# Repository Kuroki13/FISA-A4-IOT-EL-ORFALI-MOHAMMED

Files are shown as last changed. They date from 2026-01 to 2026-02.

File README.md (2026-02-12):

#  Projet IoT : "Un Campus Qui Vous Comprend"

 
 


> **Groupe 1 :** Développement et qualification d'un sous-système de contrôle environnemental (ECLSS) pour station spatiale.
>
> **Objectif :** Réalisation et validation d'un **Modèle d'Ingénierie (EM)** en environnement analogue (Salle de classe).

---

##  L'Équipe

| Membre | Rôle Technique | Responsabilités Mission |
| :--- | :--- | :--- |
| **Mohammed EL ORFALI** | Dev. Embarqué | Développement Firmware Capteur & Algorithmes de survie (Safety) |
| **Axel DELAR** | Ingénieur Radio | Protocoles de transmission & Validation Couverture Wi-Fi/4G |
| **Remy MOREEL** | Architecte Réseau | Architecture du (Gateway) & Gestion flux de données |
| **Léo SCHAEFFER** | Intégrateur Cloud | Développement du (Dashboard) & Stockage |

---

## Contexte & Problématique : "La Classe comme Station"

 



Dans une station spatiale (ISS), l'air est une ressource critique. Une augmentation du CO2 ou une baisse de pression n'est pas un simple inconfort, c'est une question de survie immédiate. Les délais de communication avec la Terre interdisent une gestion de crise 100% Cloud.

**Notre approche : Le "Module Pressurisé Autonome"**
Nous utilisons une salle de classe comme **environnement analogue** (volume clos, génération de CO2) pour qualifier un système capable de :

1.  **Survie (Edge Computing) :** Le module gère sa propre sécurité. Si le CO2 dépasse le seuil critique, l'alarme sonne **localement** et **instantanément**, sans attendre Internet.

---

## Architecture Technique (Modèle d'Ingénierie)

Le système suit une architecture IoT en couches stricte, adaptée aux contraintes spatiales simulées.



### 1. Zone de Perception
Le "Nez" du système. Il est autonome énergétiquement et décisionnellement.
* **Hardware :** Arduino (Avec ESP32) sur secteur & Powerbank (Simulation Batterie Secours).
* **Capteurs Critique :**
    * Qualité d'air : Grove Gas Sensor (MQ135 / Ref 101020078).
    * Environnement : Capteur Temp/Humidité (AM2302).
* **Sécurité :** Algorithme réflexe `IF CO2 > 1200ppm THEN Trigger_Alarm()`.
* **Protocole :** MQTT sur Wi-Fi local.

### 2. Zone Middleware
Le cerveau local du module.
* **Hardware :** PC Hôte.
* **Rôle Gateway :** Héberge le Broker MQTT (Mosquitto) et le moteur de flux (Node-RED).

### 3. Zone Application
La supervision distante pour les ingénieurs au sol.
* **Interface :** Dashboard Node-RED.
* **Données :** Télémétrie temps réel + Historique des incidents.

---

## Interface de Données

Le module transmet sa télémétrie toutes les 5 secondes sur le topic `eclss/télémetrie`.

**Format du Payload JSON :**
```json
{
        "id": "821ed53125562099",
        "type": "tab",
        "label": "GRAPHIQUES",
        "disabled": false,
        "info": "",
        "env": []
    },
    {
        "id": "c7015096d238237f",
        "type": "group",
        "z": "821ed53125562099",
        "name": "GRAPHIQUE SALLE 1",
        "style": {
            "stroke": "#000000",
            "fill": "#d1d1d1",
            "label": true,
            "color": "#000000"
        },
        "nodes": [
            "ec4d7a4e82cce2f2",
            "88a6b0668f27c40c",
            "658985ec2a1d724f",
            "656f1342826a0567",
            "46b9011460992d86",
            "f8d7d4595bd604d4",
            "945a7696eff37191"
        ],
        "x": 284,
        "y": 119,
        "w": 362,
        "h": 242
    }
}

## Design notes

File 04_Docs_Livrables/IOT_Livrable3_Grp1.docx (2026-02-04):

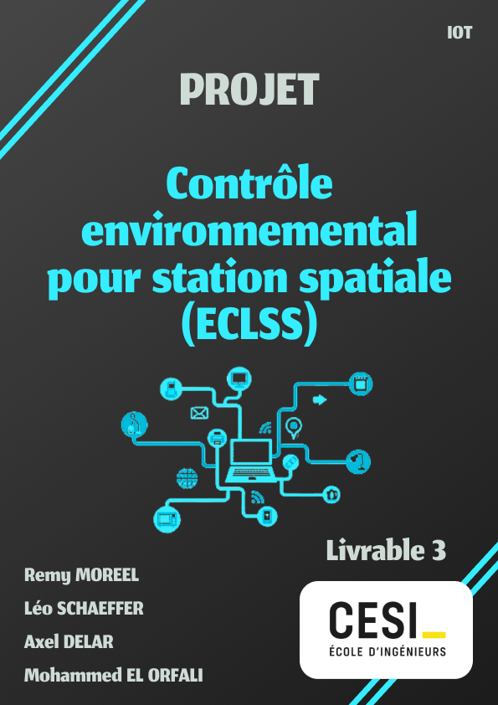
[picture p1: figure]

# Table des matières

# 1. Introduction

Après trois semaines d’analyse et de conception, ce livrable marque le passage de la théorie à la pratique. L’objectif n’est plus seulement de proposer une architecture cohérente, mais de démontrer la viabilité technique du système à travers un prototype fonctionnel.

Dans ce cadre, nous avons réalisé un Proof of Concept (POC) opérationnel mettant en œuvre une chaîne complète de communication entre capteurs, une passerelle Edge et notre consommateur, en nous appuyant sur un protocole applicatif adapté aux objets contraints. Le choix s’est porté sur MQTT, en raison de sa légèreté, de son modèle de communication publication/souscription.

Ce livrable 3 présente :

- Une démonstration fonctionnelle du flux de données (capteurs – Broker MQTT – consommateur)
- Un schéma d’architecture de communication
- Une note protocolaire justifiant les choix techniques réalisés

Enfin, il y aura également une partie sur la sécurité du prototype. Des mesures de base, inspirées des recommandations de la norme ETSI EN 303 645, ont été intégrées afin de garantir un minimum de protection pour notre dispositif.

# 2. Présentation de l’équipe

Voici notre équipe pour la réalisation de ce projet :

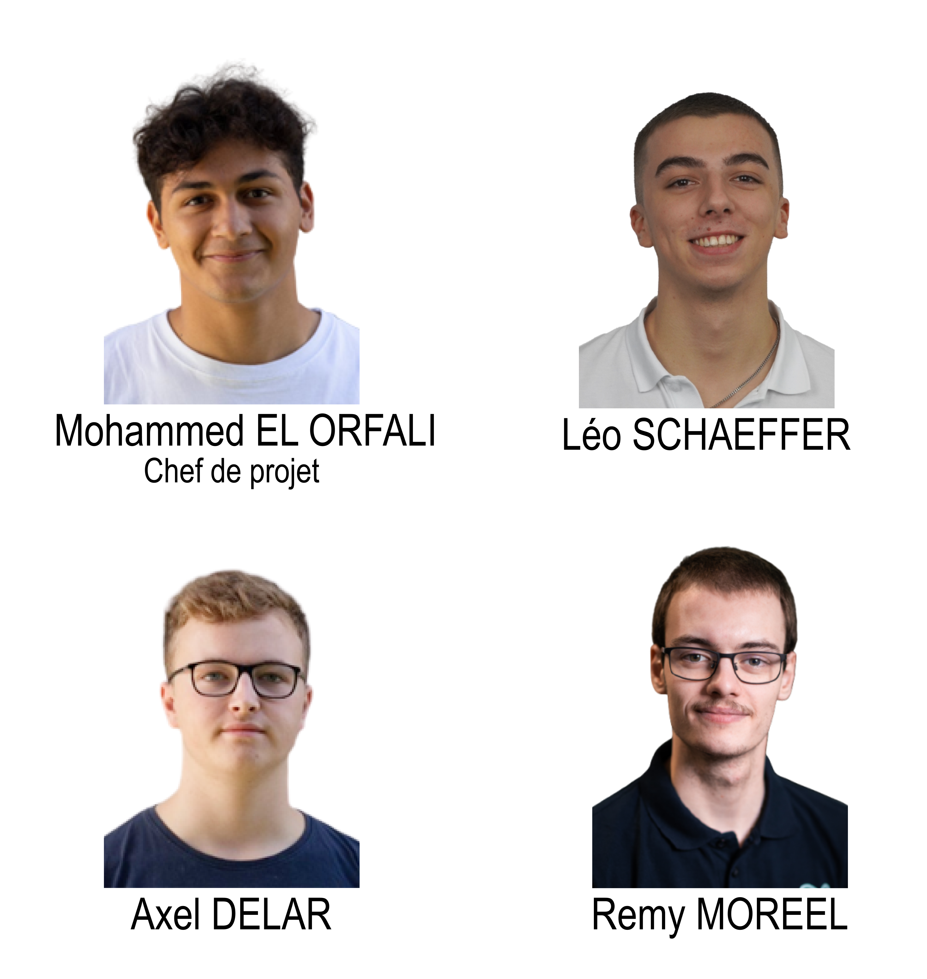
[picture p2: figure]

# 3. Schéma d’architecture de communication

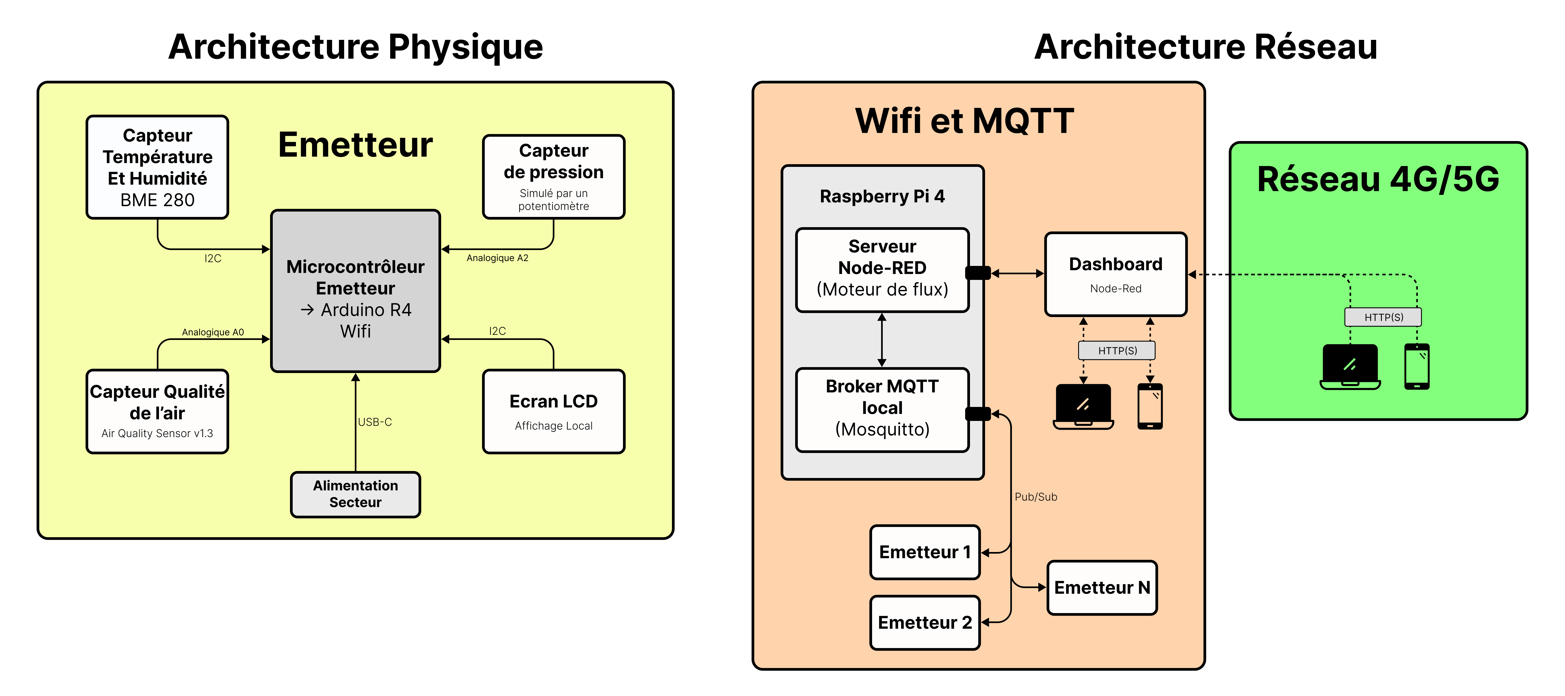
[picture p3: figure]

Ce schéma montre l’architecture globale de votre prototype, en séparant la partie physique (les objets contraints) et la partie réseau autour de MQTT.

Dans le bloc « Architecture Physique », on voit les cartes Arduino émettrices avec leurs capteurs (température/humidité BME280, qualité de l’air, pression) et l’écran LCD, tous reliés au microcontrôleur Arduino R4 WiFi qui mesure les grandeurs et publie les données.

Dans le bloc « Wifi et MQTT », la Raspberry Pi 4 joue le rôle de passerelle Edge : elle héberge le broker Mosquitto et le serveur Node‑RED qui reçoit les messages, les traite et alimente le dashboard.

Enfin, le bloc « Réseau 4G/5G » illustre l’accès distant : le dashboard Node‑RED peut être consulté depuis un smartphone ou un autre PC via HTTPS, pour visualiser en temps réel les mesures issues des Arduino publiées en MQTT.

Le déroulé complet de ce flux, depuis la mesure sur les capteurs jusqu’à l’affichage sur le dashboard, sera détaillé dans la suite du rapport.

# 4. Note protocolaire

### I) Choix protocole MQTT

Dans le cadre de ce projet, le protocole MQTT (Message Queuing Telemetry Transport) a été retenu pour assurer la communication entre les capteurs, la passerelle Edge et les consommateurs de données. MQTT est particulièrement adapté aux objets contraints, grâce à sa légèreté, à sa faible consommation de bande passante et à sa simplicité de mise en œuvre.

Le protocole repose sur un modèle publication / souscription, qui permet de découpler les producteurs de données (capteurs) des consommateurs (applications, dashboards). Ce découplage facilite l’évolutivité du système et limite les dépendances entre les composants, ce qui est particulièrement pertinent dans un contexte IoT.

Dans notre architecture, le broker MQTT Mosquitto est déployé localement sur une Raspberry Pi, qui joue le rôle de passerelle Edge. Cette passerelle centralise les échanges, assure la réception des données issues des capteurs et leur redistribution vers les consommateurs.

### II) Modèle de communication : publication/souscription

Les cartes Arduino, représentant les objets contraints du système, publient périodiquement les mesures issues des capteurs (température, pression, humidité, qualité de l’air). Ces données sont envoyées vers le broker MQTT sans connaissance directe des consommateurs.

Le dashboard Node-RED s’abonne aux topics correspondants afin de recevoir les données en temps réel. Ce modèle permet :

- D’ajouter ou de retirer des consommateurs sans modifier les capteurs,
- De centraliser le traitement au niveau de la passerelle Edge,
- De limiter les échanges inutiles sur le réseau.

Pour le moment, la communication est principalement unidirectionnelle (capteurs → consommateurs). Toutefois, l’architecture prévoit également une communication descendante (passerelle → capteurs), notamment pour le pilotage à distance d’actionneurs tels qu’un buzzer.

### III) Organisation des topics MQTT

Les topics ont été organisés selon une logique par type de donnée, avec un préfixe commun permettant d’identifier le projet :

- eclss/temperature
- eclss/pression
- eclss/humidite
- eclss/airquality
- eclss/buzzer/salle1
- eclss/buzzer/salle2

Les mesures provenant de plusieurs salles sont publiées sur un même topic, accompagnées d’un identifiant de l’Arduino émetteur dans la charge utile du message. Le tri et la séparation des données sont ensuite réalisés au niveau de Node-RED, qui filtre les messages en fonction de cet identifiant.

Ce choix nous permet :

- De limiter le nombre de topics à gérer,
- De simplifier la configuration côté capteurs,
- De centraliser la logique de traitement et de routage sur la passerelle Edge.

Les topics eclss/buzzer/salleX sont réservés à une évolution future du système, permettant l’envoi de commandes depuis le dashboard vers les capteurs afin d’activer des actionneurs à distance.

### IV) Qualité de service (QoS)

Les messages MQTT sont publiés avec un niveau de qualité de service QoS 1. Ce niveau garantit que chaque message est reçu au moins une fois par le broker et les abonnés, grâce à un mécanisme d’accusé de réception. En contrepartie, ce mode peut entraîner une duplication ponctuelle des messages, qui est gérée au niveau applicatif.

Ce choix constitue un compromis entre fiabilité et légèreté. Les données issues des capteurs sont envoyées à une fréquence d’une seconde et ne sont pas critiques au sens strict, mais une perte répétée de messages pourrait dégrader la lisibilité des mesures sur le dashboard. Le QoS 1 permet ainsi d’améliorer la fiabilité des échanges tout en conservant une charge réseau et une complexité limitée, compatibles avec un prototype IoT.

Ce niveau de QoS est également cohérent avec une architecture Edge locale, où la latence reste faible et où le surcoût induit par les accusés de réception demeure acceptable.

### V) Gestion des sessions et des messages retain

Les messages MQTT sont publiés sans option retain. Ainsi, seuls les nouveaux messages sont transmis aux abonnés, et aucune valeur précédente n’est automatiquement envoyée lors de la connexion d’un nouveau client. Ce comportement est adapté à un système où les données sont mises à jour très fréquemment et où les valeurs passées présentent peu d’intérêt.

Les clients MQTT utilisent une clean session activée. Les capteurs étant en fonctionnement continu, hormis lors de redémarrages ponctuels, il n’est pas nécessaire de conserver des sessions persistantes ou des messages en attente. Ce choix simplifie la gestion des connexions et reste cohérent avec le caractère non critique des données.

# 5. Sécurité “baseline”

D’un point de vue sécurité et cybersécurité de notre dispositif, on se base sur la norme ETSI EN 303 645. Celle-ci définit un socle dit « baseline » d’exigences en termes de cybersécurité et de protection des données, pour les objets connectées (soit, l’IoT).

La norme met à disposition 13 mesures :

- Pas de mots de passe universels par défaut : Il est évident que nous n’utilisons aucun mot de passe par défaut (123456, P@ssw0rd, admin, etc.). Chaque mot de passe utilisé dans le projet est généré aléatoirement et stocker en local dans un fichier secrets.h (non disponible sur le repository GitHub).
- Gérer les signalements de vulnérabilités : En d’autres termes, si un incident est repéré par un client ou autres, sur un objet connecté que nous avons conçu, nous avons le devoir d’y remédier.
- Maintenir le logiciel à jour : Si des mises à jour de composants, ou des failles critiques dans le logiciel sont détectées, nous avons le devoir d’en faire une mise à jour de sécurité.
- Stocker de façon sûre les paramètres sensibles : Cela se rapporte à ce qui à été mentionné dans le point 1. Toutes nos données confidentiels et paramètres (Pin des capteurs, mots de passe Wi-Fi, port MQTT, Topics de communication) sont stockées dans un fichier secrets.h local.
- Communiquer de façon sûre : Toutes nos communications sont protégées par le protocole TLS au niveau du transport, ainsi que par un chiffrement HMAC au niveau applicatif. En faisant cela, les envois/réceptions de messages sont sécurisées.
- Minimiser la surface d’attaque exposée : En d’autres termes, limité le nombre de connexions et les données envoyées. Dans notre cas, nous faisons une sélection des données avant l’envoie via MQTT dans un souci de sécurité et d’optimisation.
- Assurer l’intégrité logicielle : Pour ce cas, nous sommes entrain de mettre en place une blockchain, qui permettra la vérification de l’intégrité.
- Sécuriser les données personnelles : Dans notre cas, nous ne stockons pas de données personnelles.
- Résilience aux pannes : Nous avons choisi pour ce point d’avoir nos émetteurs sur secteur, avec une batterie de secours en cas de coupure, de même que pour le routeur que l’on utilise pour les communications en local. Ainsi, s’il y a un problème nous stockons les données en local, afin de les renvoyées lors du rétablissement.
- Exploiter la télémétrie (logs) de manière utile : Pour ce point, nous avons pour projet d’instaurer une analyse prédictive sur notre serveur Node-Red, afin de pourvoir anticiper des pannes, de mauvaises données, etc.
- Faciliter la suppression des données utilisateur : Non concernées car nous ne stockons pas de données utilisateurs.
- Rendre l’installation et la maintenance simples : Pour cela, nous avons conçu un boitier permettant l’accès facile à tous les composants. De même, ces composants sont facilement trouvables et remplaçable.
- Valider les entrées : Par exemple, prévoir les injections SQL. Nous ne sommes pas concernées par ce point car nous n’attendons aucune entrée utilisateur.

Par ces différents points, nous garantissons la sécurité aux utilisateurs de notre prototype.

# 6. PoC

Pour ce livrable, il nous était demandé de fournir une vidéo de démonstration, un Proof of Concept du projet. Pour cela, nous avons tourné une vidéo contenant une démo de flux de données, d’un Arduino émetteur vers le serveur sur Raspberry Pi, utilisant le protocole MQTT.

Cette vidéo est disponible dans le dossier Moodle de ce livrable et contient les différents détails de notre configuration MQTT (topics, QoS, journal du Broker).

Dans un premier temps, la vidéo présente les deux cartes Arduino sur lesquelles sont connectés les différents capteurs. Ces cartes représentent les objets contraints du système et sont chargées de mesurer les données physiques.

Ensuite, nous affichons sur le PC le moniteur série d’une des cartes Arduino. Cela permet de visualiser en temps réel les valeurs mesurées par les capteurs ainsi que les données qui sont envoyées vers le réseau, afin de vérifier le bon fonctionnement de la collecte et de l’émission des messages.

La vidéo se concentre ensuite sur la Raspberry Pi 4, qui joue le rôle de passerelle Edge. Celle-ci héberge le broker MQTT. Nous affichons le journal du broker en temps réel, ce qui permet d’observer directement les messages échangés, les connexions des clients et les publications sur les différents topics. À ce stade, l’ensemble des topics est affiché afin d’avoir une vision globale des échanges, même s’il serait possible de se limiter à un topic spécifique selon les besoins.

Nous présentons ensuite le point d’accès Wi-Fi, qui permet d’interconnecter l’ensemble des équipements du prototype : les cartes Arduino, la passerelle Edge et les dispositifs consommateurs. Ce réseau local constitue le support de communication du système.

Enfin, la vidéo montre l’ordinateur client sur lequel est affiché le dashboard Node-RED. Pour des raisons de simplicité de configuration, le dashboard est temporairement hébergé sur cet ordinateur, mais il sera intégré directement à la Raspberry Pi dans la version finale. On peut alors observer que les jauges du dashboard se mettent à jour en temps réel à chaque nouvelle donnée reçue via MQTT, ce qui valide le bon fonctionnement de la chaîne complète.

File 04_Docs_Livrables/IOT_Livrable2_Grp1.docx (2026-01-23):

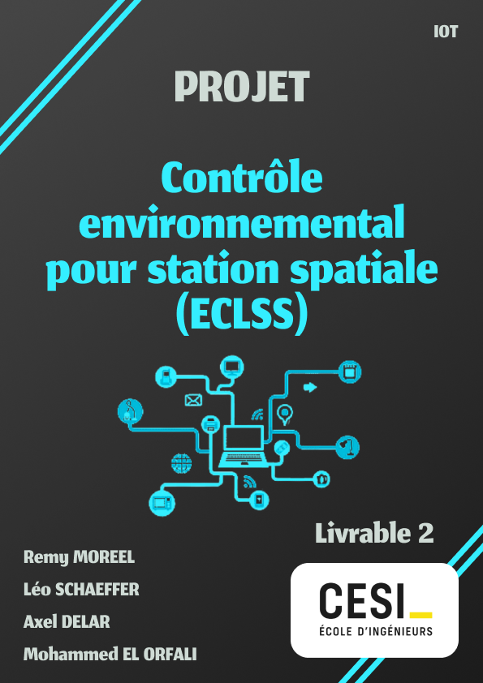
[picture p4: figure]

Livrables attendus (https://scenari.cesi.fr/scenari/cas/FISA_INFO_A4_IoT_Systemes_communicants_ERP/FISA_INFO_A4_IoT_Systemes_communicants_2526_1.html)

1. Matrice multicritère (2–3 pages) : comparaison BLE / ZigBee / Wi-Fi / LoRaWAN / NB-IoT / (Sigfox) sur : portée, débit, conso, coût, densité, dépendance opérateur, interopérabilité ; classement + justification.
2. Schéma d’architecture de communication (1 page) : couches capteur→passerelle→(Edge)→Cloud, flux montants/descendants, points de décision (temps réel vs différé).
3. Note “opérateur vs privé” (½ page) : analyse propriétaire (Sigfox/NB-IoT) vs déploiement privé (LoRaWAN) selon vos contraintes campus.
4. Trace sécurité minimale (¼ page) : “comment le choix techno respecte ETSI EN 303 645 (baseline)”.

# Table des matières

# 1. Introduction

Dans un contexte où la fiabilité, la réactivité et la continuité de service sont des exigences critiques, ce rapport présente la conception et le prototypage d’un système de surveillance IoT appliqué à un module de contrôle environnemental et de support-vie (Environmental Control and Life Support System – ECLSS).

L’objectif principal est d’assurer le monitoring en temps réel de paramètres vitaux tels que la pression, la qualité de l’air et la température, tout en garantissant une résilience élevée face aux défaillances d’infrastructure réseau ou matérielle.

Dans un premier temps, ce document expose une analyse multicritère des protocoles de communication IoT (LoRaWAN, Sigfox, Wi-Fi, LTE-M, etc.), ayant conduit au choix d’une architecture hybride Wi-Fi / LTE-M, adaptée aux contraintes de débit, de latence et de disponibilité du système.

Nous détaillerons ensuite l’architecture technique retenue, fondée sur une approche Edge-First, s’appuyant sur des composants tels que l’Arduino R4, le Raspberry Pi et la plateforme Node-RED, afin de sécuriser les flux de données et de rapprocher les décisions critiques du terrain.

Enfin, nous analyserons la conformité du système aux exigences de cybersécurité définies par la norme ETSI EN 303 645, garantissant un niveau de sécurité adapté aux environnements IoT critiques.

Présentation de l’équipe

Voici notre équipe pour la réalisation de ce projet :


# 2. Analyse Comparative et Sélection Technologique

## I. Objectif de l’analyse

Afin d’identifier la technologie la plus adaptée à notre cas d’usage, nous avons confronté les principaux protocoles du marché. Nous avons mené une analyse comparative des principaux protocoles IoT disponibles sur le marché.

Cette étude s’appuie sur les critères critiques du projet, à savoir :

- La portée de communication,
- La consommation énergétique,
- Le débit de données,
- La capacité à gérer la mobilité,
- La topologie réseau.

## II. Comparaison des protocoles IOT

Le tableau ci-dessous synthétise les caractéristiques techniques des technologies étudiées et met en évidence leurs domaines d’application.

Protocole | Catégorie | Portée | Débit | Consommation | MOBILITE | Type de réseau
Zigbee | WPAN / LAN | Courte (10-100m) | Moyen (250 kbps) | Très Faible | Non (Local) | Maillé (Mesh)
BLE | WPAN | Très courte (<50m) | Moyen (1-2 Mbps) | Très Faible | Oui (Portable) | Point-à-point / Étoile
LoRaWAN | LPWAN | Très Longue (Km) | Très Faible | Très Faible | Moyenne (Sans handover) | Étoile
Sigfox | LPWAN | Très Longue (Km) | Ultra Faible | Très Faible | Moyenne (Sans handover) | Étoile
Wi-Fi | WLAN | Moyenne (100m) | Très Élevé | Élevée | Faible (Local) | Étoile
LTE-M | LPWAN (Cellulaire) | Longue (Nationale) | Moyen (1 Mbps) | Moyenne/Faible | Excellente | Étoile (Cellulaire)
NB-IoT | LPWAN (Cellulaire) | Longue (Nationale) | Faible (250 kbps) | Faible | Mauvaise Handover | Étoile (Cellulaire)

Tableau 1 : Matrice comparative des protocoles de communication IoT

## III. Architecture réseau retenue

Au regard des contraintes de notre environnement critique (temps réel, fiabilité, évolutivité), nous avons retenu une architecture de communication hiérarchisée à deux niveaux.

Niveau local (LAN)

La couche perception communique localement via le protocole Wi-Fi.

Ce choix est motivé par :

- Une bande passante élevée,
- Une latence très faible,
- La compatibilité native IP, permettant le traitement et l’agrégation des données en temps réel sur site.

Les données sont centralisées par une passerelle IoT, basée sur un Raspberry Pi, jouant le rôle de nœud de bordure (Edge Node).

Niveau étendu (Backhaul cellulaire – optionnel)

En option, et sous réserve de disponibilité en fin de projet, une seconde liaison de communication sera mise en place afin :

- D’exfiltrer les données vers le Cloud,
- De permettre l’accès au tableau de bord à l’échelle internationale.

Dans ce scénario, la passerelle s’appuie sur une liaison LTE/4G. Ce choix de backhaul cellulaire garantit une connectivité indépendante de l’infrastructure filaire locale, assurant ainsi la continuité de service, y compris dans des environnements contraints ou isolés.

# 3. Technologies retenues

## IV. Protocole Wi-Fi

Protocole: Wi-Fi (IEEE 802.11 b/g/n/ax)

Présentation : Le standard mondial pour les réseaux locaux sans fil à haut débit. En IoT, il est utilisé pour les objets connectés au secteur nécessitant le transfert de gros volumes de données ou une interaction temps réel.

Caractéristiques techniques

Critère | Valeur
Débit | Très Élevé (11 à +1000 Mbit/s)
Portée | Moyenne (50 à 100 m)
Fréquence | 2.4 GHz / 5 GHz
Topologie | Étoile
Latence | Très Faible (ms)
Consommation | Élevée (Très élevée par rapport aux autres)
Sécurité | WPA2 / WPA3
Standard/Proprio | Standard (IEEE / Wi-Fi Alliance)

Avantages / Inconvénients

Avantages | Inconvénients
Débit énorme (vidéo possible). | Consommation d'énergie prohibitive pour les piles.
Infrastructure déjà présente partout. | Portée limitée par les murs.
Coût matériel faible et IP native. | Procédure d'appairage (SSID/Mot de passe) parfois pénible.

Cas d’usage : Caméras de surveillance, enceintes connectées, électroménager, écrans publicitaires et notre projet ECLSS

## V. Protocol LTE-M

Protocole: LTE-M (Long Term Evolution for Machines)

Présentation : Technologie cellulaire (4G) optimisée pour l'IoT. Elle utilise les antennes relais des opérateurs téléphoniques. Elle offre un compromis entre débit (suffisant pour la voix) et économie d'énergie, avec une excellente gestion de la mobilité.

Caractéristiques techniques

Critère | Valeur
Débit | Moyen-Bas (~375 kbit/s à 1 Mbit/s)
Portée | Longue (Couverture nationale 4G)
Fréquence | Bandes Licenciées (4G)
Topologie | Étoile (Cellulaire)
Latence | Faible à Moyenne (ms à s)
Consommation | Moyenne (Plus que LoRa, moins que 4G standard)
Sécurité | Carte SIM + Chiffrement Opérateur (Très haute)
Standard/Proprio | Standard (3GPP / Opérateurs)

Avantages / Inconvénients

Avantages | Inconvénients
Gère parfaitement la mobilité (Handover sans coupure). | Abonnement carte SIM payant obligatoire.
Débit suffisant pour la voix (VoLTE) et les mises à jour. | Consomme plus que Sigfox/LoRaWAN.
Qualité de service garantie (Bande licenciée). | Couverture dépendante de l'opérateur.

Cas d’usage : Traceurs de flotte de véhicules, bracelets de santé pour seniors (avec voix), terminaux de paiement mobiles et notre projet ECLSS

# 4. Stratégie de Déploiement : Réseau Opéré vs Réseau Privé

Sigfox et NB-IoT représentent des solutions propriétaires gérées par des opérateurs, tandis que LoRaWAN permet un déploiement privé autonome. Nous allons analyser les contraintes typiques d'un campus (superficie limitée ~1-5 km², bâtiments denses, besoins en fiabilité pour capteurs IoT comme tracking d'actifs ou monitoring énergétique, budget modéré). Pour un campus, le privé offre contrôle mais demande investissement initial, contre la simplicité des opérateurs au prix de dépendance. Pour notre projet nous n’utiliserons pas ces technologies et nous n’avons pas exactement le même contexte que le campus.

## I. Opérateur Propriétaire : Sigfox

Sigfox utilise un réseau mondial propriétaire ultra-basse consommation pour messages courts (12 octets). Déploiement pas optimisé côté campus, car opérateur gère l'infrastructure via abonnements (~1-2€/an/capteur).

## VI. Opérateur Propriétaire : NB-IoT

NB-IoT est une technologie cellulaire 4G/5G LPWAN des opérateurs comme Orange ou SFR, avec bonne pénétration en intérieur. Pas de déploiement local requis, facturation par data (~0.5-5€/an/capteur selon volume). Convient aux campus urbains couverts, avec QoS garantie mais coûts récurrents élevés pour gros volumes.

## VII. Déploiement Privé : LoRaWAN

LoRaWAN est open-source, déployé en privé via 1-3 passerelles (~500-5000€ chacune) couvrant un campus entier. Contrôle total (sécurité, QoS), bidirectionnel, scalable jusqu'à 1000s capteurs sans abonnement externe. Rentable dès 300 appareils, parfait pour contraintes campus (couverture indoor/outdoor personnalisée).

## VIII. Tableau Comparatif

Critère | Sigfox (Propriétaire) | NB-IoT (Propriétaire) | LoRaWAN (Privé)
Déploiement Campus | Aucun (réseau opérateur) | Aucun (réseau cellulaire) | 1-3 passerelles (1-2 mois setup)
Coût Initial (100 capteurs) | 500-1500€ modules + abos | 1000-3000€ modules + abos | 2500-17000€ (CAPEX only)
Coût Récurrent | 3000-6000€/5ans | Moyen-élevé par data | Zéro (propriétaire)
Couverture Campus | Bonne si zone opérateur | Excellente indoor (pénétration) | Optimale (ajustable)
Débit/Bidirectionnel | Faible uplink only ~100msg/j | Moyen, bidir. fiable | Élevé, bidir. configurable
Contraintes Campus | Dépendance opérateur, faillites passées | Couverture variable rurale | maintenance IT

En conclusion, aucune de ces solutions (Sigfox, NB-IoT propriétaires ou LoRaWAN privé) ne s'avère pas adaptée aux contraintes spécifiques d'un campus ou d'un espace clos. Elles ont toutes des limites en termes de coût récurrent ou de dépendance externe. Des alternatives comme Wi-Fi ou réseaux mesh zigbee conviendraient mieux pour une maîtrise optimale dans cet environnement.

# 5. Architecture de Communication et Flux de Données

Cette section détaille l'architecture technique mise en place pour le système ECLSS. Elle repose sur une architecture IoT modulaire divisée en 4 zones fonctionnelles, allant de la perception physique jusqu'à la visualisation distante via réseau cellulaire.

## I. Schéma d’architecture global

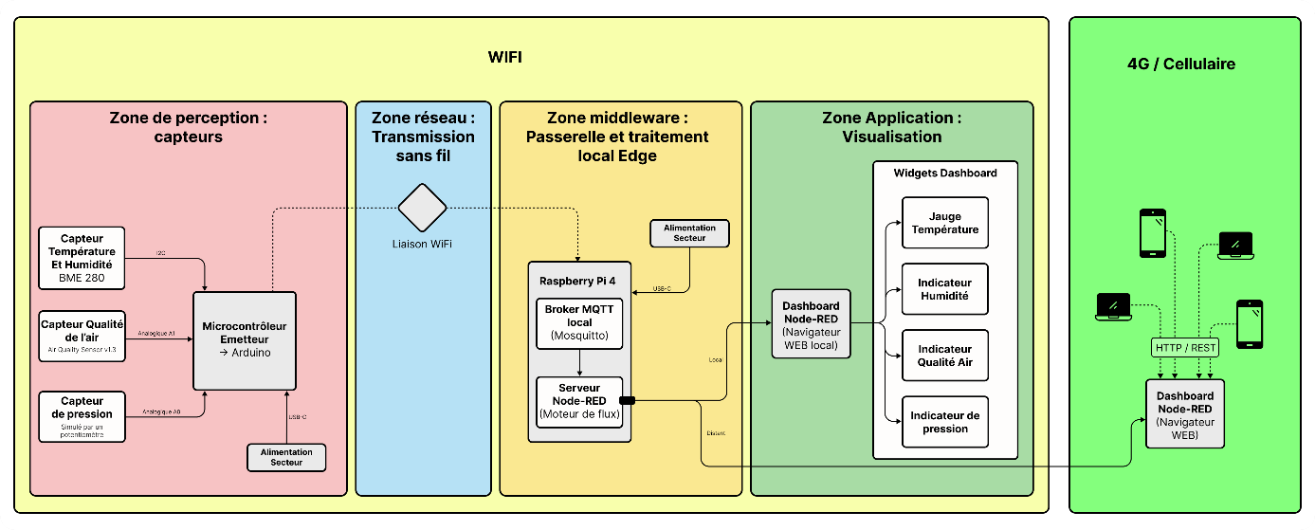
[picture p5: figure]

Figure 1 : Architecture global

## IX. Description des Zones

1. Zone de Perception (Capteurs)

- Matériel : Microcontrôleur Arduino (Emetteur).
- Instrumentation :
  - BME 280 : Mesure de la température et de l'humidité (Liaison I2C).
  - Air Quality Sensor v1.3 : Mesure de la qualité de l'air (Liaison Analogique A1).
  - Capteur de Pression (Simulé) : Surveillance de la pressurisation cabine (Liaison Analogique A0).
- Rôle : Acquisition des données brutes, conversion numérique et transmission vers la passerelle.

2. Zone Réseau (Transmission)

- Protocole : Wi-Fi (IEEE 802.11).
- Fonction : Assure le transport sans fil des messages MQTT entre le microcontrôleur et la passerelle. Cette zone crée un réseau local (LAN) dédié à la station.

3. Zone Middleware (Edge Computing)

- Support : Raspberry Pi 4 (Alimenté sur secteur).
- Composants Logiciels :
  - Broker MQTT (Mosquitto) : Agit comme le chef d'orchestre des données. Il reçoit les publications de l'Arduino et les distribue.
  - Serveur Node-RED : Moteur de flux qui traite les données, applique la logique métier (seuils d'alerte) et héberge l'interface graphique.
- Rôle : Cette couche "Edge" permet un traitement local des données critiques, garantissant une autonomie du système même sans connexion internet.

4. Zone Application & Connectivité 4G

- Visualisation : Dashboard Node-RED accessible via navigateur Web. Il affiche les jauges (Température, Humidité, Qualité Air, Pression) en temps réel.
- Accès Distant (4G/Cellulaire) : L'interface est rendue accessible à l'extérieur (Smartphones, PC portables) via une liaison HTTP/REST sur le réseau cellulaire. Cela permet la supervision de la station depuis n'importe quel point du globe (Terre).

## X. Flux de Données et Points de Décision

L’architecture repose sur une stratégie de défense en profondeur, dans laquelle les décisions critiques sont prises au plus près du matériel, tandis que les fonctions d’analyse, de supervision et de contrôle à distance sont déportées vers la passerelle Edge et, le cas échéant, vers le Cloud.

### Nœud capteur – Zone de perception (Arduino R4)

Le nœud capteur constitue le premier niveau de traitement (Edge Computing – Niveau 0). Il est responsable des réactions immédiates et de l’acquisition des données brutes.

Action A – Sécurité réflexe (Hard Real-Time)

Cycle de traitement : Lecture analogique (A0 – pression) → comparaison avec le seuil critique → si pression < 980 hPa → activation immédiate des actionneurs locaux (LED rouge, buzzer).

Justification : Cette boucle de sécurité s’exécute en moins de 1 ms et fonctionne de manière totalement autonome. Elle garantit une alerte immédiate de l’équipage, même en cas de :

- Coupure du réseau Wi-Fi,
- Défaillance de la passerelle Raspberry Pi.

Ce mécanisme assure ainsi une résilience maximale du système.

Action B – Télémétrie

Cycle de traitement : Lecture des capteurs (I2C / analogique) → sérialisation des données au format JSON (ex. {"ID_MAC": 3D-0F-FJ-EK-FJ, "val" : "980"}) → publication MQTT sur le topic eclss/pressure.

Fréquence :

- Envoi périodique toutes les 2 secondes afin de limiter la charge réseau.
- Envoi immédiat en cas de déclenchement d’alarme.

### Réseau local – Zone de transmission (Wi-Fi)

Rôle : Assurer le transport des messages JSON entre le nœud capteur et la passerelle Edge.

Caractéristiques : Contrairement aux protocoles LPWAN (LoRa, Sigfox), le Wi-Fi est maintenu en mode actif (Keep-Alive).

Avantages :

- Latence de transmission très faible (< 10 ms),
- Capacité à transporter des charges utiles importantes (trames JSON complètes),
- Absence de fragmentation ou de compression complexe.

### Passerelle / Middleware – Zone Edge (Raspberry Pi 4)

Le Raspberry Pi agit comme le centre de coordination du système et le point de transition vers l’extérieur.

Rôle 1 – Broker et distribution (Mosquitto)

- Réception des messages MQTT en provenance de l’Arduino.
- Distribution des messages aux abonnés locaux :
  - Node-RED

Rôle 2 – Visualisation et logique métier (Node-RED)

- Décodage des messages JSON.
- Mise à jour en temps réel des jauges du Dashboard local.

Rôle 3 – Passerelle WAN

- Exposition sécurisée de l’interface Web du Dashboard.
- Accès distant possible via la liaison cellulaire 4G/LTE-M.

### Réseau étendu – Zone WAN (4G / LTE-M)

Technologie :

- Partage de connexion via USB (tethering),
- Ou modem LTE-M sous forme de HAT.

Rôle : Fournir un backhaul Internet indépendant de l’infrastructure filaire locale.

Fonctionnalités :

- Accès au Dashboard Node-RED depuis un terminal distant (smartphone, PC),
- Utilisation d’une adresse IP publique ou d’un tunnel VPN/Cloud sécurisé.

### Flux descendant – Télécommande (Utilisateur → Capteur)

Ce flux permet l’interaction humaine à distance et le contrôle du système.

Interface utilisateur : Depuis un smartphone connecté en 4G, l’opérateur sélectionne l’action « Acquitter l’alarme » sur le Dashboard Web.

Traitement côté passerelle :

- Node-RED reçoit la requête HTTP,
- Génération d’un message MQTT de commande (ex. {"cmd": "RESET"}),
- Publication sur le topic eclss/control.

Exécution côté capteur :

- L’Arduino, abonné au topic, reçoit la commande via sa fonction callback (),
- Désactivation immédiate du buzzer et retour à l’état nominal.

# 6. Conformité et Sécurité (ETSI EN 303 645)

Le choix technologique du projet a été guidé par les exigences de sécurité de base définies par la norme ETSI EN 303 645, qui vise à renforcer la cybersécurité des objets connectés.

Tout d’abord, l’authentification repose sur des identifiants uniques par utilisateur, avec des mots de passe chiffrés via un algorithme robuste (comme bcrypt), conformément à l’exigence interdisant les mots de passe par défaut et faibles.

Les communications entre le client et le serveur seront sécurisés par HTTPS (TLS), garantissant la confidentialité et l’intégrité des données échangées. Les données sensibles stockées côté serveur sont protégées par des mécanismes de chiffrement et des contrôles d’accès basés sur les rôles comme SSH.

Enfin, l’architecture applicative limite l’exposition des services (principe du moindre privilège) et évite toute surface d’attaque inutile. Ainsi, le choix des technologies et des mécanismes de sécurité mis en place répond aux exigences minimales (baseline) de l’ETSI EN 303 645 en matière d’authentification, de protection des données, de communication sécurisée et de maintenabilité

# 7. Conclusion

En conclusion, le Wi-Fi s'affirme comme le choix technologique optimal pour notre système ECLSS, offrant une latence extrêmement faible (inférieure à 10 ms), un débit élevé compatible avec les flux JSON temps réel et une connectivité simple à mettre en place avec notre Raspberry PI. De plus nous pourrions par exemple ajouter des caméras sur notre système et nous serions en capacité de retransmettre les images grâce à cette solution. Cette solution garantit une résilience maximale en environnement contrôlé, avec une sécurité WPA3 et une infrastructure souvent préexistante, surpassant les LPWAN pour nos besoins critiques de monitoring (température, pression, qualité d'air). À terme, nous prévoyons d'ajouter une liaison 4G pour un accès distant sécurisé au dashboard Node-RED, permettant une supervision mobile depuis n'importe où sans altérer la performance locale.

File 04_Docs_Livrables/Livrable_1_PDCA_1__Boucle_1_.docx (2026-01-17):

Template Livrable 1

PDCA 1 (Boucle 1)

- Titre : Diagnostic & cadrage - “Un campus qui vous comprend”
- Équipe : Mohammed EL ORFALI, Axel DELAR, Remy MOREEL, Léo SCHAEFFER
- Groupe : 1
- Espace étudié : Salle de classe
- Date : 16/01/2026
- Référent pédagogique : DING Yuehua
- Version : V1

### 0) Résumé exécutif (≤ 8 lignes)

Problème observable : Surveillance environnementale critique (CO₂, T, Pa, etc…) impossible en temps réel à cause de la volatilité des connexions réseaux et de l'absence d'intelligence locale.

Besoins fonctionnels (SMART) : Collecte de données multi-capteurs, alertes locales immédiates (Edge), transmission résiliente vers le Cloud.

Contraintes clés (latence, énergie, réseau, sécurité) : Latence faible (<1s) pour les alertes, continuité de service (Store & Forward) en cas de coupure réseau, interopérabilité.

Pré-choix d’architecture : Hybride (Edge + Cloud). Justification : Permet la réactivité locale (sécurité) via la Gateway tout en assurant la supervision globale via le Cloud.

### 1) Observation & problème observable

Contexte/zone : Salle de classe ou laboratoire (assimilé à un "Module Habitat" critique). Flux d'étudiants variable, fenêtres fermées (risque CO₂).

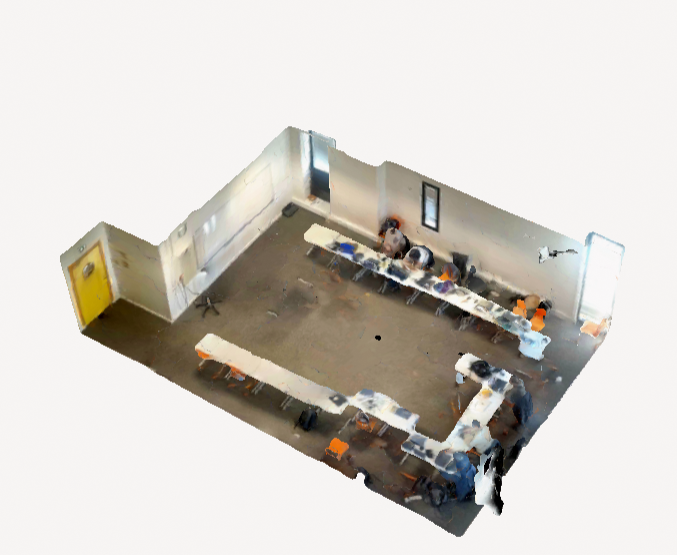
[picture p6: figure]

Faits mesurables : Temp, Pression (fermeture de porte), Infrarouge x2 (entrée sortie d’une salle), Capteur Air qualité (CO2)

Problème formulé : Comment adapter la qualité de l’air et la température en fonction de la fréquentation de la salle ? Comment garantir l’intégrité des pièces grâce à la pression exercé et à la fréquentation ?

Bénéficiaires / personas : Service de maintenance, Responsables sécurité, Occupants de la salle.

Indicateurs de performance clés (KPI) :

- Taux de perte de paquets : 0 %, garanti par la gestion du buffer.
- Latence d’alerte locale : inférieure à 100 ms.
- Temps de commutation entre Wi-Fi et 4G : inférieur à 5 secondes.

### 2) Besoins fonctionnels (SMART)

B1 : Le nœud capteur doit mesurer T°, Pression, CO₂ et Présence toutes les 5 secondes et transmettre à la passerelle via réseau local basse conso.

B2 : Le nœud capteur doit déclencher une alerte locale autonome (LED/Buzzer) instantanément si le CO₂ dépasse 1200 ppm, assurant la sécurité même en cas de coupure réseau.

B3 : Le système doit stocker localement les données (Buffer) si le réseau est coupé et les transmettre intégralement dès le rétablissement (Store & Forward).

### 3) Contraintes & hypothèses

Latence / criticité locale : Critique pour l'alerte CO₂ (Besoin temps réel). Tolérante pour l'historique Cloud.

Énergie / autonomie : Alimentation continue (Secteur/Powerbank) permettant une écoute permanente et une réaction locale.

Réseau / couverture : Wi-Fi couvert local 100m & étendu avec répéteur. Couverture 5G transmission cloud.

Interopérabilité : Format de données standardisé (JSON) sur protocole MQTT.

Sécurité (baseline) : Sécurité basique à base de Wi-Fi (https, bloque de port, etc…)

Hypothèses (ce qu’on suppose vrai à ce stade) : Sécurité hypothétique.

### 4) Benchmark d’architectures (Cloud / Edge / Hybride)

Option | Schéma rapide | Latence | Sobriété | Simplicité | Limites | Go / No-Go
Cloud | Capteur -> Wi-Fi -> Cloud | Élevée (dépend du réseau) | Faible (Wi-Fi énergivore) | Haute | Aucune alerte si panne internet | No-Go
Edge | Tout en local (Pas de remontée) | Très Faible (Temps réel) | Haute | Moyenne | Pas d'historique ni de vision globale | No-Go
Hybride | Capteur -> Gateway -> Cloud | Faible (Locale) / Haute (Distante) | Optimale (WI-FI local) | Facile | Complexité logicielle (Sync) | GO

Analyse & choix provisoire :

Choix de l'architecture Hybride. Elle seule répond à la double exigence du professeur : réactivité immédiate (Edge) pour les alertes de sécurité et centralisation des données (Cloud) pour le dashboard, avec une robustesse face aux coupures.

### 5) Comparatif techno communication (LTN/LPWAN vs courte-portée)

Famille | Exemples | Portée | Débit | Conso | Coût/infra | Remarques - cas d’usage
LPWAN | LoRa, Sigfox, LTE-M | Très longue (km) | Très faible | Très faible | Élevé (Gateway LoRa) | Inadapté (Latence trop élevée, Duty Cycle limité)
Courte-portée | Zigbee, Wi-Fi, BLE | Courte/Moyenne | Moyen/Haut | Faible | Faible | Retenu. Wi-fi idéal pour capteurs sur batterie (Mesh/Star).

### 6) Comparatif techno communication (Zigbee vs WI-FI)

Famille | Exemples | Portée | Débit | Conso | Coût/infra | Remarques - cas d’usage
Courte-portée | Zigbee | Courte/Moyenne | Moyen/Haut | Faible | ~=Élevé | Même fréquence mais plus compliqué à mettre en place.
Courte-portée | Wi-Fi | Courte/Moyenne | Moyen/Haut | Moyenne | Moyenne mais besoin potentielle de répéteur | Retenu. Wi - Fi idéal pour capteurs sur batterie pour ça rapidité.

Conclusion multicritère : Le Wi-Fi est retenu pour sa simplicité et son débit, mais nécessitera une gestion stricte du Deep Sleep pour préserver la batterie. Le 4G sera utilisé uniquement pour le lien Gateway ↔ Cloud (Backhaul).

### 7) Risques initiaux & mesures

Techniques :

- Risque : Saturation du Buffer mémoire sur l’Arduino en cas de coupure longue.
- Mesure : Implémentation d'un buffer circulaire (écrasement des plus vieilles données) ou stockage sur carte SD.

Sécurité :

- Risque : Injection de fausses données capteurs.
- Mesure : Wi-Fi local.

Opérationnels :

- Risque : Déconnexion du secteur.
- Mesure : Le Powerbank agit comme un onduleur (UPS) pour maintenir le système en vie.

### 8) Synthèse & pré-choix

Architecture retenue (provisoire): Architecture Distribuée Hybride (Wi-Fi intégrée + Gateway Edge Intelligence).

Pourquoi ?

Pour garantir la sûreté de fonctionnement (Safety) via le Edge et la disponibilité des données (Telemetry) via le Cloud, indépendamment de l'état du réseau.

Famille techno pressentie : Capteurs sur Arduino + Wi-fi intégrée vers Gateway Arduino (Modem 4G simulé/réel).

Exigences sécurité minimales : Sécurité Wi-fi basique, MQTTS (TLS) vers le cloud, Authentification Gateway.

Schéma de principe (image intégrée ou lien) :

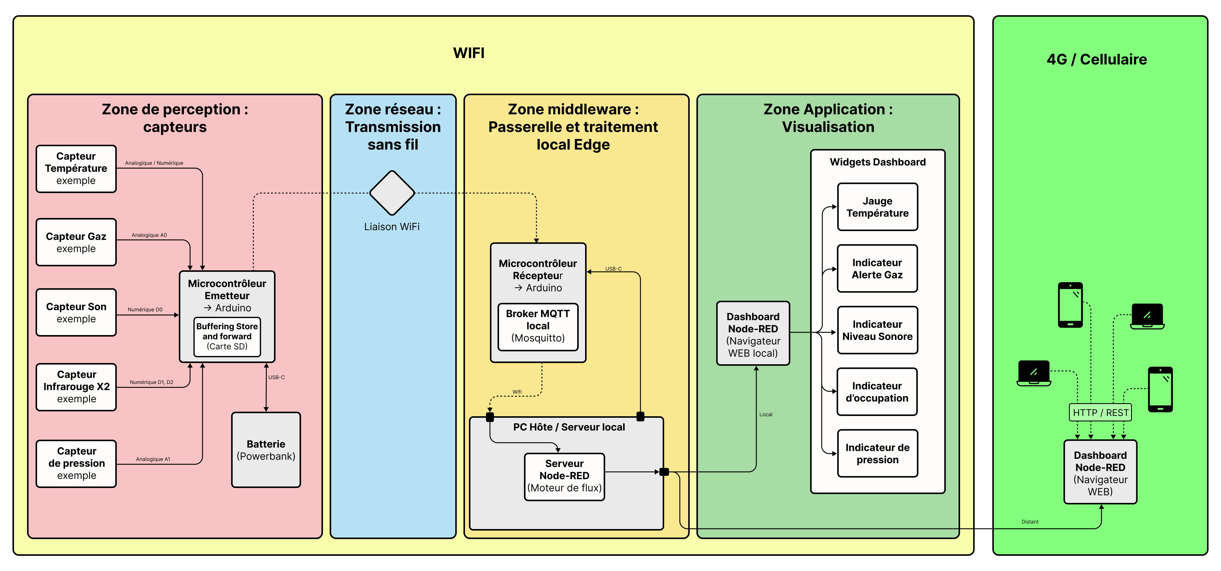
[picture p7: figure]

  Flux de Données :
  1. Nœud Capteur (Smart Sensor) :
- Action A (Sécurité Locale - Edge Computing) : Mesure (CO2) -> Comparaison Seuil interne (si >1200ppm) -> Activation immédiate du Buzzer/LED (Latence < 1ms, indépendante du réseau).
- Action B (Télémétrie) : Formatage JSON -> Publish MQTT sur topic campus/salle1/air.
  2. Réseau Local (Wi-Fi) :
- Transport du message JSON vers la Gateway.
- Avantage secteur : Connexion Wi-Fi maintenue active (pas de temps de réveil/négociation), envoi quasi-instantané.
  3. Gateway (Concentrateur & Buffer) :
- Rôle Principal (Store & Forward) : Reçoit MQTT -> Vérifie la connexion WAN (4G).
  - Cas 1 (Connecté) : Transmet immédiatement au Cloud.
  - Cas 2 (Coupure) : Stocke les données localement (Tampon circulaire/SD) et réessaie plus tard.
  4. Réseau WAN :
- Modem 4G -> Internet (Backhaul).
  5. Cloud :
- Broker MQTT Cloud -> Base de données -> Visualisation (Node-RED Dashboard).

### 9) Références

Template Livrable 1

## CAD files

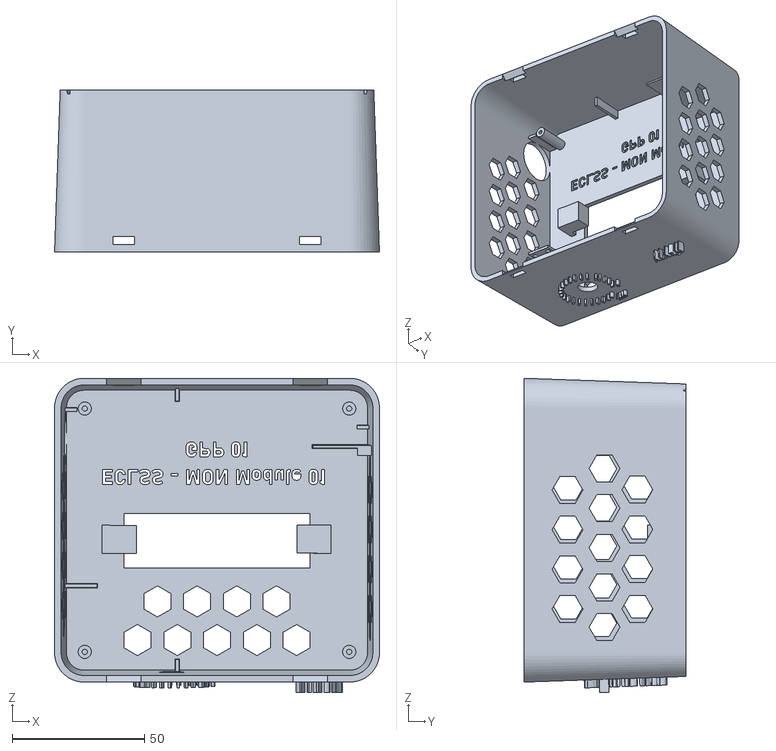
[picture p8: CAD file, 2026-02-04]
04_Docs_Livrables/CAD Project/DM-049-P-1_v6.STL
122.9 x 61.2 x 118.9

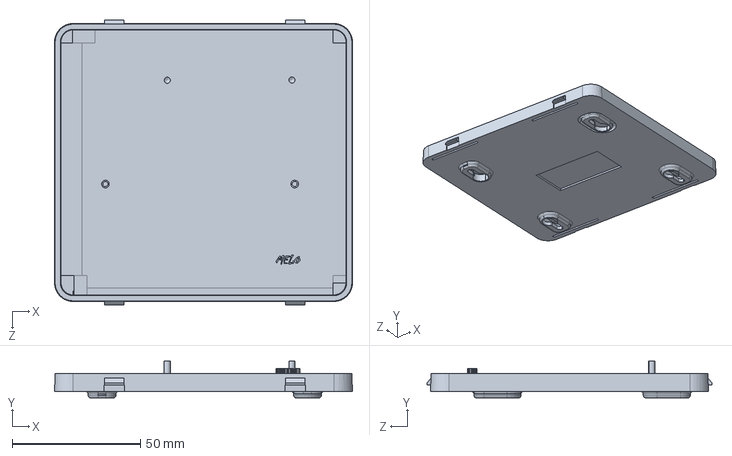
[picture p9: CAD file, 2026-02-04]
04_Docs_Livrables/CAD Project/DM-049-P-2 v3.SLDPRT
116.0 x 14.4 x 110.9 mm

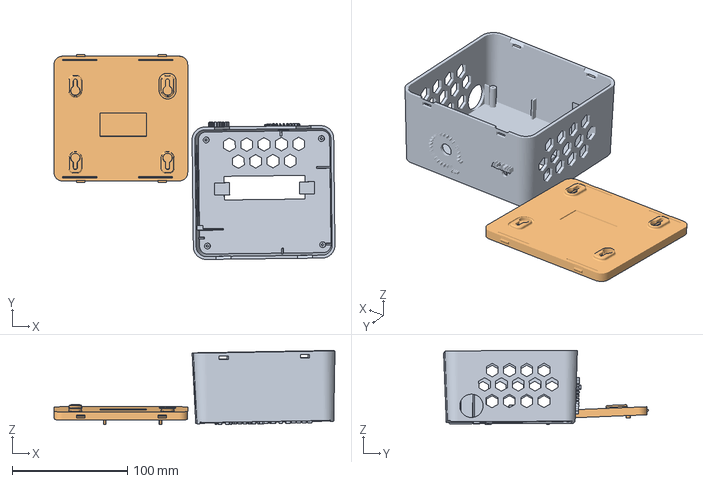
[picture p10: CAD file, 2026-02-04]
04_Docs_Livrables/CAD Project/DM-049-P-1_v5.3mf
243.7 x 177.7 x 64.2 mm
DM-049-P-1_v5.STL
DM-049-P-2 v5.STL

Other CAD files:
04_Docs_Livrables/CAD Project/DM-049-P-1_v4.SLDPRT
04_Docs_Livrables/CAD Project/DM-049-P-2 v6.STL
04_Docs_Livrables/CAD Project/DM-049-P-2 v5.STL
04_Docs_Livrables/CAD Project/DM-049-P-1_v4.STL
04_Docs_Livrables/CAD Project/DM-049-P-1_v5.STL

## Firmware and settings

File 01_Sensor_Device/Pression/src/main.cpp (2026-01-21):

#include <Arduino.h>

// Configuration du capteur pression
const int pressureSensorPin = A0; // Pin analogique pour le capteur de pression
const bool mode_Simulation = false; // true pour mode simulation, false pour mode réel

//-- Simulation --
// Si true : La pression change toute seule (vague)
// Si false : Tu tapes la pression dans le moniteur série
const bool mode_Auto=true; 


// Seuille de sécurité (ECLSS) pour la pression (en hPa)
const float PRESSION_NOMINALE = 1013.25; // Pression standard au niveau de la mer
const float PRESSION_SEUIL_BAS = 980.0;  // Seuil bas de pression (fuite possible)
const float PRESSION_SEUIL_HAUT = 1050.0; // Seuil haut de pression (surpression possible)


// Variable globales
float pressionActuelle = 0.0;

// -- Simulation -- Variable globale qui stocke notre "Pression Virtuelle"
float pressionSimulee = PRESSION_NOMINALE;

bool alarmeActivee = false;


 // Les fonctions de gestion de la pression 

 /** --Simulation--
  * 0. SIMULATION DE PRESSION (optionnel)
  * Si on est en mode simulation, on fait varier la pression simulée.
  * Sinon, on lit la pression depuis le capteur.
  */

  void GenererPressionSimulee(){
	if(mode_Auto){
		// OPTION 1 : Simulation Automatique (Sinusoïde)
    // Fait varier la pression entre 900 et 1100 hPa toutes les 10 secondes
    // Utilise le temps (millis) pour générer une onde

	float temps = millis() / 1000.0; // Temps en secondes
	pressionSimulee = 1000.0 + (100.0 * sin(temps)); // Variation sinusoidale

	// Ajout d'un peu de "bruit" aléatoire pour faire réaliste (+/- 1 hPa)
    pressionSimulee += random(-100, 100) / 100.0;

	} else {
		// OPTION 2 : Simulation Manuelle (Moniteur Série)
		if (Serial.available() > 0){
			float valeurLue = Serial.parseFloat();
			// Serial.parseFloat() retourne 0.0 s'il ne comprend pas ou lit juste "Entrée"
      		// On ignore donc les 0.0 sauf si on veux vraiment simuler le vide spatial
			if (valeurLue >= 10.0){
				pressionSimulee = valeurLue;
				Serial.print(">>> COMMANDE RECUE : Pression forcée à ");
				Serial.print(pressionSimulee);
				Serial.println(" hPa");
			}

			// Nettoyer le buffer série
			while (Serial.available() > 0) {
				Serial.read();
			}
		}

	};
 }

 /**
 * 1. ACQUISITION & FILTRAGE
 * Lit le capteur X fois et fait une moyenne pour supprimer le bruit.
 */

 int lireValeurBrutePression(){
	long somme = 0;
	int nombreEchantillons = 10; // On fait la moyenne de 10 lectures

	for (int i = 0; i < nombreEchantillons; i++){
		somme += analogRead(pressureSensorPin);
		delay(2); 
	}

	return somme / nombreEchantillons;
 }

 /**
 * 2. CONVERSION (Calibration)
 * Transforme la valeur 0-1023 en hPa.
 * Note : Pour le SPX3058D, c'est ici qu'il faudra ajuster les valeurs min/max.
 */

 float convertirEnPression(int valeurBrute){
	if(mode_Simulation){
		// Si on simule, on map 0-1023 vers 900-1100 hPa pour tester les alarmes
		return map(valeurBrute, 0, 1023, 900, 1100);
	}

	// --- FORMULE REELLE (A calibrer avec un baromètre de référence) ---
  	// Exemple théorique : 0.5V = 0 hPa, 4.5V = 2000 hPa
  	// Sur Arduino R4 (ADC 10-bit par défaut) :
  	// Voltage = (valeurBrute / 1023.0) * 5.0;
  	// Pression = (Voltage - Offset) * ScaleFactor;

	// On va utiliser une mapping linéaire simple pour le test :
  	// Supposons que le capteur sort entre 0 et 1023 pour 0 à 2000 hPa
  	float hpa = (valeurBrute / 1023.0) * 2000.0; 
  	return hpa;
 }

 /**
 * 3. LOGIQUE DE SECURITE
 * Vérifie si on est en danger.
 */

 void verifierSecurite(float pression){
	if (pression < PRESSION_SEUIL_BAS){
		if (!alarmeActivee){
			Serial.println("!!! ALERTE : DEPRESSURISATION DETECTEE !!!");
			alarmeActivee = true;
		}
	} else if (pression > PRESSION_SEUIL_HAUT){
		if (!alarmeActivee){
			Serial.println("!!! ALERTE : SURPRESSION DETECTEE !!!");
			alarmeActivee = true;
		}
	} else {
		if (alarmeActivee){
			Serial.println("Pression revenue à la normale. Alarme désactivée.");
			alarmeActivee = false;
		}
		

	}


 }
 
 void setup() {
	Serial.begin(9600);
	Serial.println("\n--- DEMARRAGE SIMULATEUR ECLSS ---");
	pinMode(pressureSensorPin, INPUT);
	Serial.println("--- Capteur Pression Initialisé ---");

	if (!mode_Simulation){
		Serial.println("Mode Réel Activé : Lecture depuis le capteur de pression.");
	} else {
		Serial.println("Mode Simulation Activé : Génération de pression virtuelle.");
		if(mode_Auto){
			Serial.println(" - Simulation Automatique (Sinusoïde)");
		} else {
			Serial.println(" - Simulation Manuelle (Moniteur Série)");
			Serial.println("   -> Entrez une valeur de pression (hPa) et appuyez sur Entrée.");
		}
	}
}

void loop(){
	float raw;
	// -- Simulation --
	if (mode_Auto){
		GenererPressionSimulee();
		pressionActuelle = pressionSimulee;
		Serial.print(">>> PRESSION SIMULEE : ");
		Serial.println(pressionActuelle);
	} else {
		// Acquisition & Filtrage
	int raw = lireValeurBrutePression();
	// Conversion
	pressionActuelle = convertirEnPression(raw);
	Serial.print(">>> PRESSION MESUREE : ");
	Serial.println(pressionActuelle);
	}

	//Vérification de la sécurité
	verifierSecurite(pressionActuelle);

	// Télémétrie (Debug)
	Serial.print("Valeur Brute : ");
	Serial.print(raw);
	Serial.print(" | Pression: ");
	Serial.print(pressionActuelle);
	Serial.println(" hPa");

	delay(1000); // Attente avant la prochaine lecture

}

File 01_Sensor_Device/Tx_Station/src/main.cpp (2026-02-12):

#include <Arduino.h>
#include <WiFiS3.h>
#include <PubSubClient.h>
#include <ArduinoBearSSL.h>
#include <LiquidCrystal_I2C.h>
#include "Sensors.h"
#include "secrets.h"
#include "WDT.h"



bool isMqttConnected = false;

int statusWiFi;

uint8_t MAC_ADDRESS[6];
char STR_MAC_ADDRESS[18];

WiFiClient wifiClient;
PubSubClient mqttClient(wifiClient);
LiquidCrystal_I2C lcd(LCD_SCREEN_I2C,16,2);

void setup()
{
	Serial.begin(9600);
	WDT.begin(8000);
	while (!Serial);
	Serial.println("------------------------");
	initBme280();
	lcd.init();
	lcd.noBacklight();
	ErrorLEDsInit();

	// Connexion WiFi
	statusWiFi = WL_IDLE_STATUS;
	while (statusWiFi != WL_CONNECTED)
	{
		Serial.print("Connexion to ");
		Serial.println(WIFI_SSID);

		statusWiFi = WiFi.begin(WIFI_SSID, WIFI_PASS);
		Serial.print("Status = ");
		Serial.println(statusWiFi);
		if(statusWiFi != WL_CONNECTED) {
			Serial.println("WiFi not connected, check the modem!");
			delay(5000);
			Serial.println("Trying to reconnect to the WiFi ...");
		}
		CheckErrorsLED(statusWiFi);
	}

	while (WiFi.localIP() == INADDR_NONE) delay(100);

	Serial.println("WiFi connected!");
	Serial.println("IP : " + WiFi.localIP().toString());

	WiFi.macAddress(MAC_ADDRESS);
	snprintf(STR_MAC_ADDRESS, sizeof(STR_MAC_ADDRESS),"%02X:%02X:%02X:%02X:%02X:%02X",MAC_ADDRESS[0], MAC_ADDRESS[1], MAC_ADDRESS[2], MAC_ADDRESS[3], MAC_ADDRESS[4], MAC_ADDRESS[5]);

	Serial.print("Device ID (MAC): ");
	Serial.println(STR_MAC_ADDRESS);
	
	// Configuration MQTT
	mqttClient.setServer(MQTT_SRV_ID, MQTT_SRV_PORT);

	// Initial LED status
	CheckErrorsLED(statusWiFi);
}

void connexionMQTT()
{
	char clientId[32];
	snprintf(clientId,sizeof(clientId),"UNO_R4_Client_%s}",STR_MAC_ADDRESS);

	if (mqttClient.connect(clientId))
	{
		Serial.println("MQTT connecté !");
		Serial.println(clientId);
		isMqttConnected = true;
	}
	else
	{
		Serial.println("MQTT échec");
		isMqttConnected = false;
		delay(5000);
	}
}

void computeHMAC(const char* message, char* outputHex)
{
	uint8_t hmac[32]; // SHA-256 = 32 bytes

	br_hmac_context ctx;
	br_hmac_key_context keyCtx;

	br_hmac_key_init(&keyCtx, &br_sha256_vtable, HMAC_KEY, strlen(HMAC_KEY));
	br_hmac_init(&ctx, &keyCtx, 0);
	br_hmac_update(&ctx, message, strlen(message));
	br_hmac_out(&ctx, hmac);

	// conversion hex
	for (int i = 0; i < 32; i++){
		sprintf(outputHex + (i * 2), "%02x", hmac[i]);
	}
	outputHex[64] = '\0';
}


void sendMQTTMessage(float data, const char *topic)
{
	char dataStr[10];
	dtostrf(data, 0, 2, dataStr);


	char *p = strstr(dataStr, ".00"); //trim le .00
	if (p) *p = '\0';

	// chaîne à signer
	char signBuffer[64];
	snprintf(signBuffer, sizeof(signBuffer),"id=%s&data=%s", STR_MAC_ADDRESS, dataStr);

	// HMAC
	char hmacHex[65];
	computeHMAC(signBuffer, hmacHex);

	// payload final
	char payload[160];
	snprintf(payload, sizeof(payload),
		"{\"id\":\"%s\",\"data\":%s,\"hmac\":\"%s\"}",
		STR_MAC_ADDRESS, dataStr, hmacHex);

	mqttClient.publish(topic, payload);

	Serial.println("MQTT envoyé :");
	Serial.println(payload);
}

void loop()
{
	statusWiFi = WiFi.status();
	WDT.refresh();
	if (!isMqttConnected)
	{
		connexionMQTT();
	}
	mqttClient.loop();
	if (isMqttConnected && statusWiFi == WL_CONNECTED)
	{
		lcd.backlight();
		Serial.println("------------------------");

		float temp = getTemp();
		lcd.setCursor(0,0);
		lcd.print(temp);
		lcd.setCursor(5,0);
		lcd.print("C");

		float hum = getHum();
		lcd.setCursor(9,0);
		lcd.print(hum);
		lcd.setCursor(14,0);
		lcd.print("%H");

		float press = getPress();
		lcd.setCursor(0,1);
		String printPress = String((int) press);
		while (printPress.length() < 4) printPress = " " + printPress;
		if (press == 0) printPress = "Err ";
		lcd.print(printPress);
		lcd.setCursor(4,1);
		lcd.print("hPa");

		float airQual = getAirQual();
		lcd.setCursor(9,1);
		lcd.print(airQual);
		lcd.setCursor(14,1);
		lcd.print("%A");


		sendMQTTMessage(temp, TOPIC_TEMPERATURE);
		sendMQTTMessage(hum, TOPIC_HUMIDITE);
		sendMQTTMessage(press, TOPIC_PRESSION);
		sendMQTTMessage(airQual, TOPIC_AIR_QUAL);

		// SERIAL
		Serial.print("Actual temperature (°C): ");
		Serial.println(temp);
		Serial.print("Actual humidity (%): ");
    	Serial.println(hum);
		Serial.print("Actual pressure (hPa): ");
		Serial.println(press);
		Serial.print("Actual air quality (%): ");
		Serial.println(airQual);

		CheckErrorsLED(statusWiFi);
		delay(2000);
	}
}

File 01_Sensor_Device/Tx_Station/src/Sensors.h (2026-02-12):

#include <Adafruit_BME280.h>
#include <Arduino.h>
#include "secrets.h"

///////////////////////////////////////////
// TEMPERATURE AND HUMIDITY SENSOR (BME280)
///////////////////////////////////////////

Adafruit_BME280 bme;

bool errorTempHum = false;
bool errorPress   = false;
bool errorAir     = false;

/**
 * @brief Inititalize the BME280 sensor 
 * @return None
 * @param None
*/
void initBme280()
{
    unsigned status;
    // Initialisation capteur BME280 et vérification connexion
    status = bme.begin(BME280_SENSOR_I2C);
    if (!status)
    {
        while (!status)
        {
            Serial.println("Could not find a valid BME280 sensor, check wiring!");
            Serial.print("SensorID was: 0x");
            Serial.println(bme.sensorID(), 16);
            delay(5000);
            Serial.println("Trying to reconnect to the BME280 sensor ...");
            status = bme.begin(BME280_SENSOR_I2C);
        }
    }
    Serial.println("BME280 sensor connected!");
}

/**
 * @brief Retrieve temperature from BME280 sensor
 * @return Float : temperature level in C°
 * @param None
*/
float getTemp()
{
    float temp = bme.readTemperature();

    // Error checking
    if (isnan(temp) || temp <= 0 || temp >= 180)
    {
        errorTempHum = true;
        return 503; // valeur fallback
    }

    errorTempHum = false;
    return temp;
}

/**
 * @brief Retrieve humidity from BME280 sensor
 * @return Float : humidity level in %
 * @param None
*/
float getHum()
{
    float hum = bme.readHumidity();


    // Error checking
    if (isnan(hum) || hum <= 0 || hum >= 100)
    {
        errorTempHum = true;
        return 0;
    }

    errorTempHum = false;
    return hum;
}


///////////////////////////////////////////
// PRESSURE SENSOR
///////////////////////////////////////////


// /**
//  * @brief Inititalize the pressure sensor 
//  * @return None
//  * @param None
// */

// // --- Variables de configuration ---
// // Alpha : 0.1 = Lissage fort (courbe très douce), 1.0 = Brut (très nerveux)
// const float FILTER_ALPHA = 0.1;
// float filteredPressure = 1013.0; 

// /**
//  * @brief Initialize the pressure sensor
//  */
// void InitPression()
// {
//     pinMode(PRESSURE_SENSOR_PIN, INPUT);
//     int raw = analogRead(PRESSURE_SENSOR_PIN);
//     filteredPressure = (raw / 1023.0) * 1200.0;
// }

// /**
//  * @brief Retrieve pressure with Anti-Ghosting & Exponential Smoothing
//  * @return float : Stable pressure level in hPa
//  */
// float getPress()
// {
//     int sensorValue = analogRead(PRESSURE_SENSOR_PIN);
    
//     float rawHPa = (sensorValue / 1023.0) * 1200.0; 

//     if (rawHPa < 900 || rawHPa > 1170)
//     {
//         errorPress = true;
// 		filteredPressure = (FILTER_ALPHA * rawHPa) + ((1.0 - FILTER_ALPHA) * filteredPressure);
// 		return filteredPressure; 
//     }
//     errorPress = false;

//     // Formule : NouvelleMoyenne = (10% de la Nouveauté) + (90% de l'Historique)
//     filteredPressure = (FILTER_ALPHA * rawHPa) + ((1.0 - FILTER_ALPHA) * filteredPressure);

//     return filteredPressure;
// }


/**
 * @brief Calculate 
 * @return Int : 
 * @param None
*/
int lireValeurBrutePression()
{
	long somme = 0;
	int nombreEchantillons = 10; // On fait la moyenne de 10 lectures

	for (int i = 0; i < nombreEchantillons; i++)
	{
		somme += analogRead(PRESSURE_SENSOR_PIN);
		delay(2);
	}

	return somme / nombreEchantillons;
}

/**
 * @brief Simulate pressure with potentiometer 
 * @return Float : pressure level in hPa
 * @param None
*/
float getPress()
{
    float valeurBrute = lireValeurBrutePression();
    float press = (valeurBrute / 1024.0) * 1200.0;

    // Error checking
    if (press < 900 || press > 1170)
    {
        errorPress = true;
        return press;
    }

	if (press <= 100)
	{
		errorPress = true;
		return 0;
	}

    errorPress = false;
    return press;
}


///////////////////////////////////////////
// AIR QUALITY SENSOR
///////////////////////////////////////////

// const float FILTER_ALPHA_AIR = 0.05; 
// float filteredAirQuality = 0.0; 
// const float standardVoltage = 100;
// float currentVoltage = 400;

// /**
//  * @brief Initialize the air quality sensor
//  */
// void InitAirQual()
// {
//     analogRead(AIR_QUAL_SENSOR_PIN); 
//     delay(2);
//     filteredAirQuality = analogRead(AIR_QUAL_SENSOR_PIN);
// }

// /**
//  * @brief Retrieve air quality from air quality sensor
//  * @return Float : air quality level in %
//  * @param None
// */
// float getAirQual() {

//     currentVoltage = analogRead(AIR_QUAL_SENSOR_PIN);
    


//     // Error checking
//     if (currentVoltage < 0 || currentVoltage > 1023)
//     {
//         errorAir = true;
//         return filteredAirQuality;
//     }

//     errorAir = false;	
// 	filteredAirQuality = (FILTER_ALPHA_AIR * currentVoltage) + ((1.0 - FILTER_ALPHA_AIR) * filteredAirQuality);

// 	float percentVoltage = (filteredAirQuality/1024) * 100;

//     return filteredAirQuality;
// }

const float standardVoltage = 100;
float currentVoltage = 400;

/**
 * @brief Retrieve air quality from air quality sensor
 * @return Float : air quality level in %
 * @param None
*/
float getAirQual() {
    float lastVoltage = currentVoltage;
    currentVoltage = analogRead(AIR_QUAL_SENSOR_PIN);
    float percentVoltage = (currentVoltage/1024) * 100;

    Serial.print("Actual air quality (%): ");
    Serial.print(percentVoltage);

    if (currentVoltage - lastVoltage > 400 || currentVoltage > 700) {
        Serial.println(". High pollution! Force signal active.");
    }
    else if ((currentVoltage - lastVoltage > 400 && currentVoltage < 700) || currentVoltage - standardVoltage > 150) {
        Serial.println(". High pollution!");
    }
    else if (( currentVoltage - lastVoltage > 200 && currentVoltage < 700) || currentVoltage - standardVoltage > 50) {
        Serial.println(". Low pollution!");
    }
    else {
        Serial.println(". Fresh air.");
    }

    // Error checking
    if (currentVoltage < 0 || currentVoltage > 1023)
    {
        errorAir = true;
        return 0;
    }

    errorAir = false;
    return currentVoltage;
}


///////////////////////////////////////////
// ERROR LEDS FUNCTIONS
////////////////////////////////////////////

inline void ErrorLEDsInit()
{
    pinMode(RED_PIN, OUTPUT);
    pinMode(BLUE_PIN, OUTPUT);
    pinMode(YELLOW_PIN, OUTPUT);
}

void setColor(uint8_t red, uint8_t blue, uint8_t yellow)
{
    analogWrite(RED_PIN, red);
    analogWrite(BLUE_PIN, blue);
    analogWrite(YELLOW_PIN, yellow);
}

void CheckErrorsLED(int statuus){
    if(errorTempHum){
		setColor(255, 0, 0);
        tone(BUZZER_PIN, 440, 500);
	} else if (errorPress){
		setColor(0, 255, 0);
        tone(BUZZER_PIN, 440, 500);
	} else if (errorAir){
		setColor(255, 255, 0);
        tone(BUZZER_PIN, 440, 500);
	} else if(statuus != WL_CONNECTED){
        setColor(255, 0, 0);
        tone(BUZZER_PIN, 440, 10000);
    }
    else {
		setColor(0, 0, 255);
        noTone(BUZZER_PIN);
	}
}

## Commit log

2026-01-17 Création de l'architecture projet
2026-01-17 Révision du README avec les détails du projet et de son architecture
    Mise à jour du titre du projet et ajout d’informations détaillées sur le projet, les rôles de l’équipe, le contexte, l’architecture technique et les spécifications de l’interface de données.
2026-01-17 Ajout de documentation et de liens pour les capteurs et les livrables
    Ajout de fichiers de documentation PDF et DOCX pour le capteur AM2302 et les livrables du projet, ainsi que de liens raccourcis vers Arduino Playground et la documentation du capteur de pression SPX3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
2026-01-20 Ajouter le projet PlatformIO initial pour le routeur WiFi
    Création d'un nouveau projet PlatformIO pour un routeur WiFi (point d'accès) basé sur Arduino, comprenant la configuration, le code source et les fichiers de documentation. Le fichier main.cpp config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
2026-01-20 le projet PlatformIO initial pour l'intégration SPX3058
    Projet PlatformIO pour l'intégration du capteur SPX3058. Ajout d'une structure de répertoires de base, de fichiers de configuration et d'un exemple main.cpp avec une fonction de remplacement. Documen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
2026-01-20 Ajouter une simulation de capteur de pression et une logique de sécurité
    Développement du fichier main.cpp avec lecture du capteur de pression, simulation (automatique/manuelle) et logique de seuil de sécurité pour les alertes de dépressurisation et de surpression. Ajout 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
2026-01-21 Ajout projet PlatformIO initial pour le capteur MQTT
    Ajout d'un nouveau projet PlatformIO pour « Projet_La Classe comme Station_Tx_Coeur », comprenant des fichiers de configuration, le code source pour la connectivité WiFi et MQTT, ainsi qu'une structu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
2026-01-21 Ajout d'un module capteur de pression et l'intégrer dans la boucle principale
    Introduction de Sensor_Pressure.h pour la gestion des capteurs de pression, y compris la simulation et la logique de sécurité. Intégration de l'acquisition des données de pression dans la boucle prin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
2026-01-21 Ajout de la publication MQTT des données de pression non bloquantes
    Introduit un mécanisme basé sur une minuterie pour envoyer les données du capteur de pression sous forme de charges utiles JSON au sujet MQTT « eclss/salle1/pression » toutes les 2 secondes. Ajoute u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
2026-01-21 feat: connexion wifi + mqtt avec le capteur de pression
    Reorganized MQTT connection handling into a separate function, simplified message sending, and moved pressure data publishing to its own function. Updated MQTT server address and removed unused varia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
2026-01-22 refacto: refactoring de main.cpp
2026-01-22 Refactory Sensor_Pressure.h
    Suppression de tout le code lié à la simulation de pression, y compris les indicateurs de mode de simulation, la génération de pression simulée et la sortie série associée. Le code ne prend désormais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
2026-01-22 Ajout température + modification MAIN
    - ajout récupération température
    - ajout récupération humidité
    - modification main : méthode globale et modulable pour les requetes MQTT
2026-01-23 Ajout de l'addresse MAC dans le payload des messages MQTT et dans la connexion client au broker MQTT
    [main.cpp]
2026-01-29 Add I2C addresses in secrets.h file
2026-01-30 Debut Rework sensors et led
    [Sensor_Pressure.h, Sensors.h, main.cpp]
2026-02-03 Creation Error et modification fichiers
    [Sensors.h, main.cpp]
2026-02-03 Modification temperature
2026-02-03 Add CAD models & deliverables; enable monitor echo
    Add multiple CAD assets for the sensor device (DM-049-P-1 v4/v5/v6 and DM-049-P-2 v3/v5/v6 as SLDPRT/STL/3mf formats) and project deliverables (IOT_Livrable3 docx/pdf, video and archive). Update 01_S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
    [DM-049-P-1_v4.SLDPRT, DM-049-P-1_v4.STL, DM-049-P-1_v5.3mf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]
2026-02-04 relocate CAD files
    [DM-049-P-1_v4.SLDPRT, DM-049-P-1_v4.STL, DM-049-P-1_v5.3mf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]
2026-02-09 fix: trim la sortie du air quality pour le hmac
    [main.cpp]
2026-02-12 init block chain
2026-02-12 Update section title for Zone de Perception
    Removed 'Smart Sensor' from the section title for clarity.
2026-02-12 Refine pressure validation and show 'Err' on zero
    Adjust pressure handling and LCD output for sensor errors.
    - Sensors.h: For readings outside the normal range (press < 900 or > 1170) keep errorPress=true but return the raw pressure instead of 0. Add a special-case for extremely low readings (press <= 100) to mark an actual sensor fault (errorPress=true) and return 0.
    - main.cpp: When pressure equals 0, display "Err " on the LCD to indicate a sensor error.
    These changes let the system distinguish between anomalous measurements and clear sensor failures, while surfacing raw out-of-range values for debugging.
    [Sensors.h, main.cpp]
